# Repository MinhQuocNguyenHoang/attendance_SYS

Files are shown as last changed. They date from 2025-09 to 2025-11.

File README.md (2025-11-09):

# IoT Attendance System

## Overview
This is an IoT-based attendance system built using an ESP32 microcontroller.  
The device scans RFID cards to record attendance information (Card ID + Timestamp) and uploads the data in real time to Google Sheets for storage and monitoring.

**Future enhancements:** integrating fingerprint authentication for additional security and flexibility.

## Hardware Used
- MCU: ESP32 (WiFi + Bluetooth)
- RFID Module: RC522 (SPI)
- LCD: 16x02 via I2C
- Power supply + voltage regulator
- Custom PCB designed with Altium Designer

## Software Environment
- Language: Embedded C
- Framework: ESP-IDF v5.4.1
- RTOS: FreeRTOS real-time kernel
- Tools: VS Code, Altium Designer (PCB design)
- Library: abobija_rc522

## Project Structure
```
    attendance_SYS/
    ├─ attendance_SYS_altium/ # PCB design / schematic
    ├─ attendance_system/ # MCU code
    ├─ README.md # This file
    ├─ demo_IOT_attendance_sys.mp4 # Demo video
    ├─ layout.pdf # PCB layout
    └─ schematic.pdf # Schematic
```

## Features
- Scan RFID cards and verify card IDs
- Log attendance time (RTC or NTP sync)
- Upload attendance data to Google Sheets
- Wi-Fi provisioning via BLE
- FreeRTOS task flow:
    1. Read rfid
    2. Send data to google sheet via https method GET

## Wiring / Schematic
- [PCB Layout](./layout.pdf) 
- [Schematic](./schematic.pdf) 

## Getting Started
1. Install ESP-IDF 
2. Setup Google Sheets API: [Google Sheet](https://docs.google.com/spreadsheets/d/ 1bOf_m6btDb6PRxpN6TObC4pNcN5I2Ge17Xd1aixpjCk/edit?usp=sharing) 
3. Connect USB cable to flash and monitor ESP32 

```bash
git clone https://github.com/MinhQuocNguyenHoang/attendance_SYS.git
cd attendance_SYS/attendance_system
idf.py set-target esp32
idf.py build
idf.py flash monitor
```

## Demo
A demonstration video is included:
[Demo Video](./demo_IOT_attendance_sys.mp4)

## Testing
Scan RFID card → Data should instantly appear in Google Sheets<br> 
Test Wi-Fi Provisioning → Device must reconnect automatically

## Roadmap / Future Improvements
- Add fingerprint sensor for secure attendance 
- Retry & error handling to prevent data loss 
- Build a mobile/web dashboard for data visualization 
- Improve data security with message encryption
- OTA firmware to ESP32  

## Author
Nguyễn Hoàng Minh Quốc<br>
GitHub: @MinhQuocNguyenHoang

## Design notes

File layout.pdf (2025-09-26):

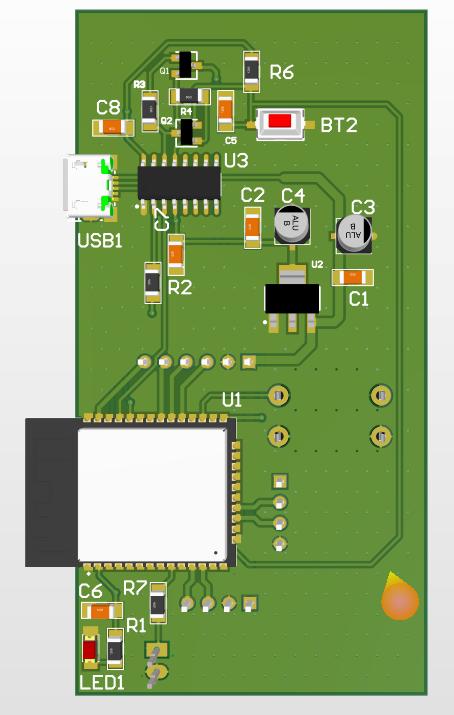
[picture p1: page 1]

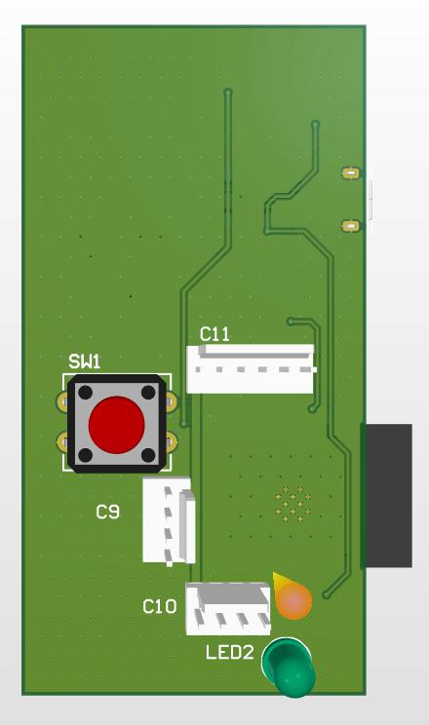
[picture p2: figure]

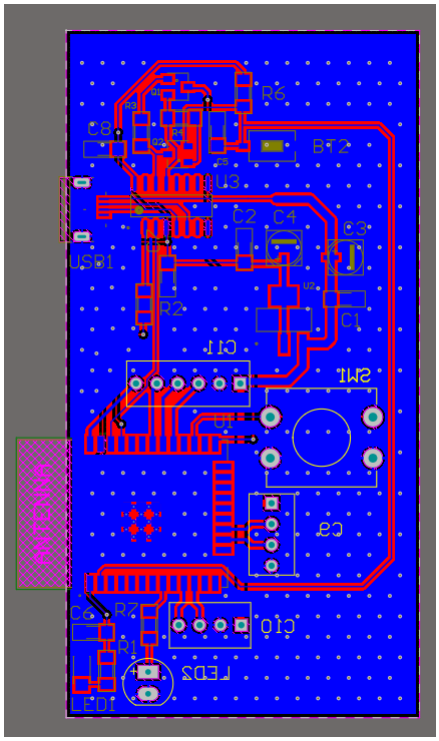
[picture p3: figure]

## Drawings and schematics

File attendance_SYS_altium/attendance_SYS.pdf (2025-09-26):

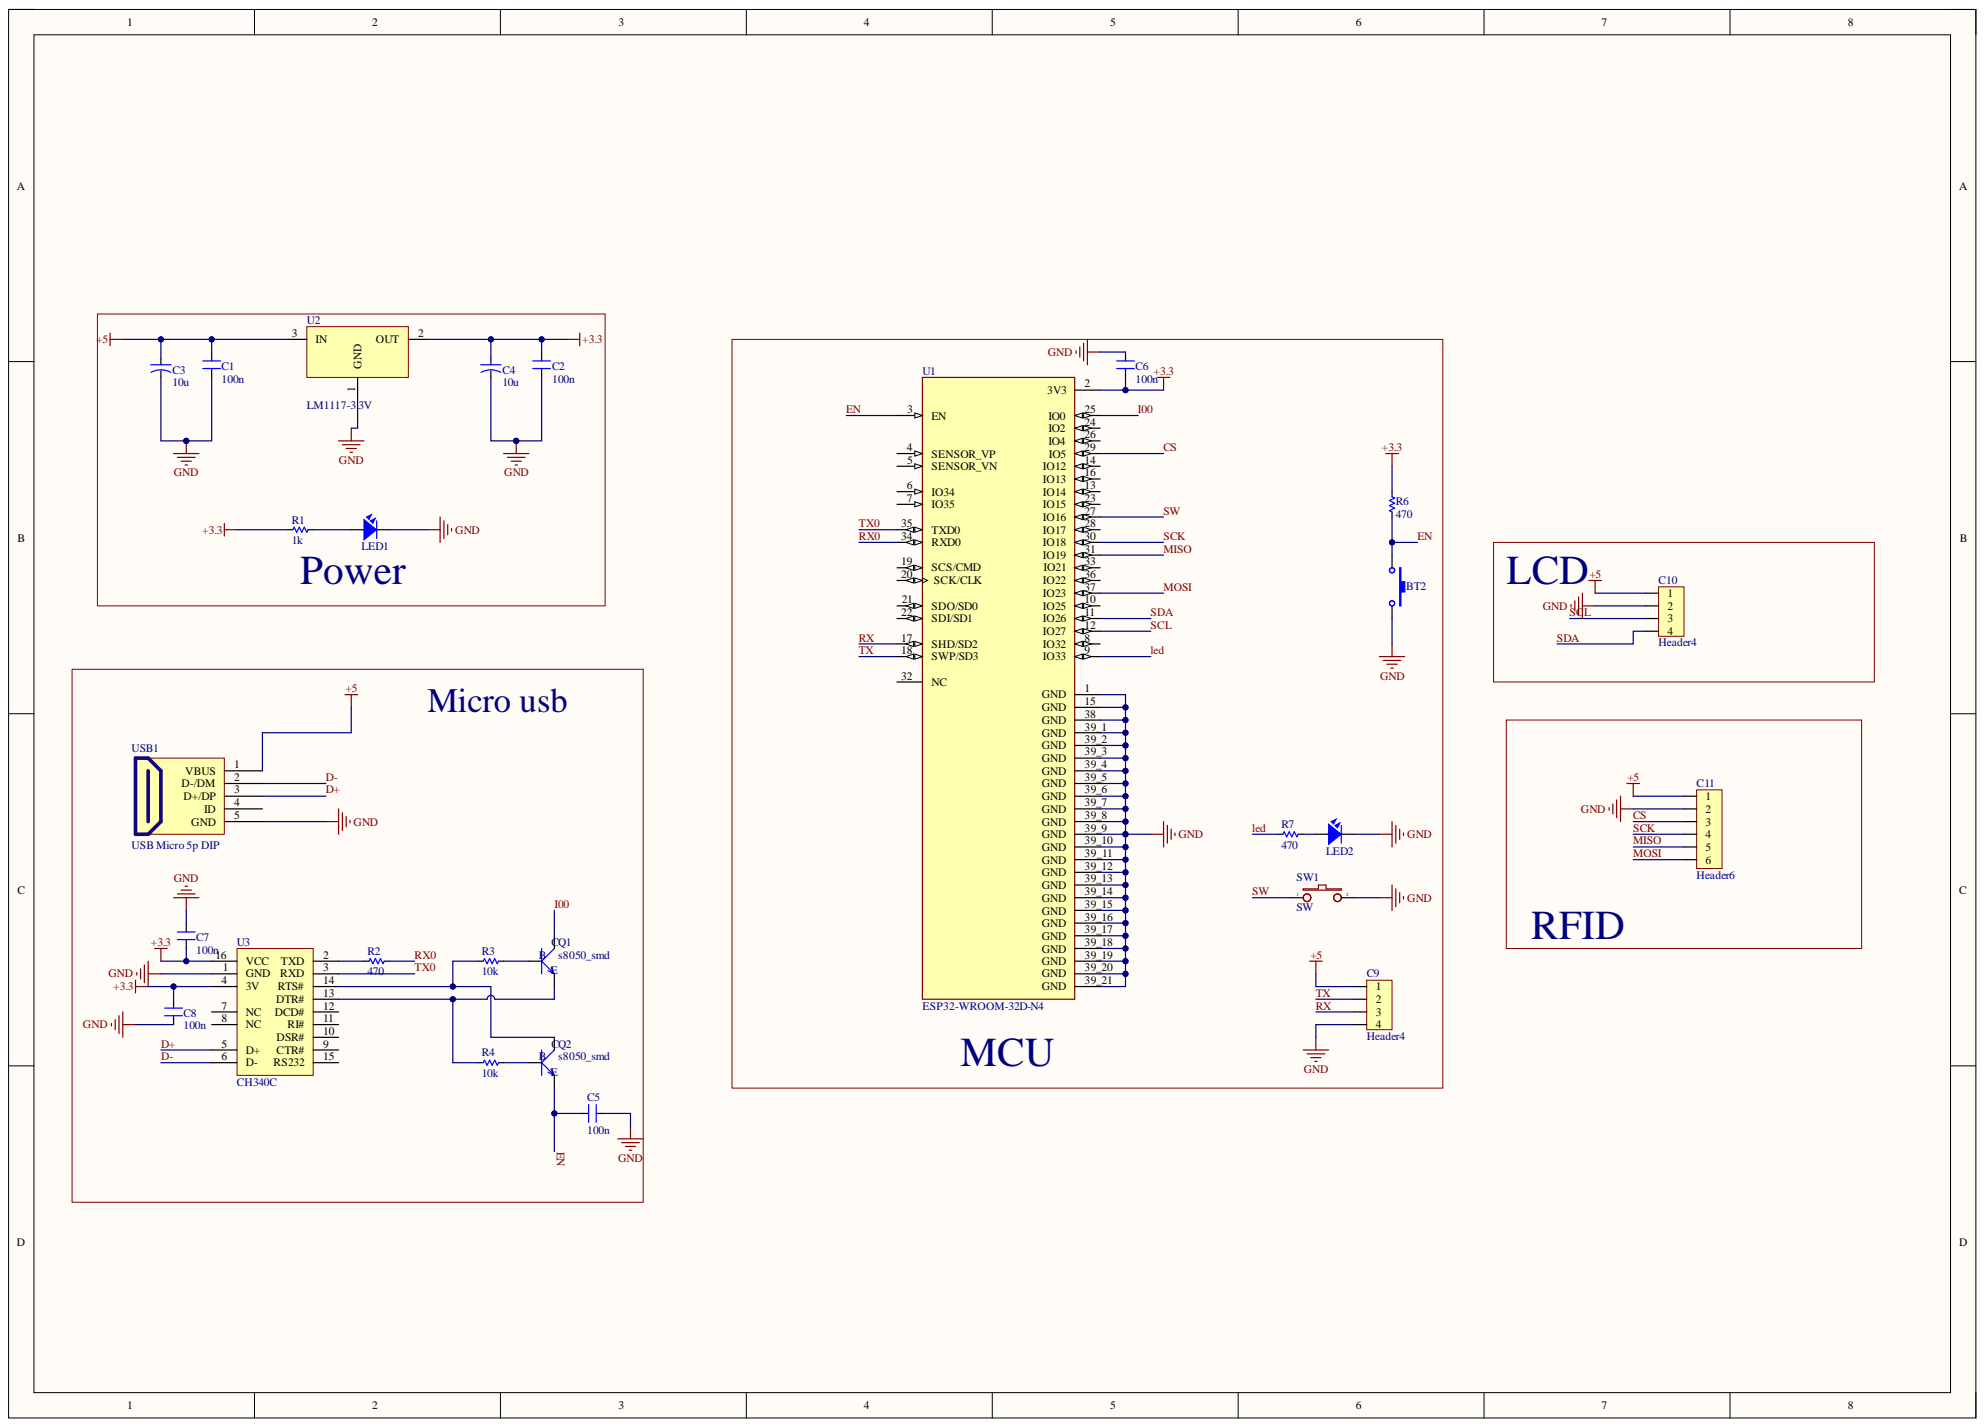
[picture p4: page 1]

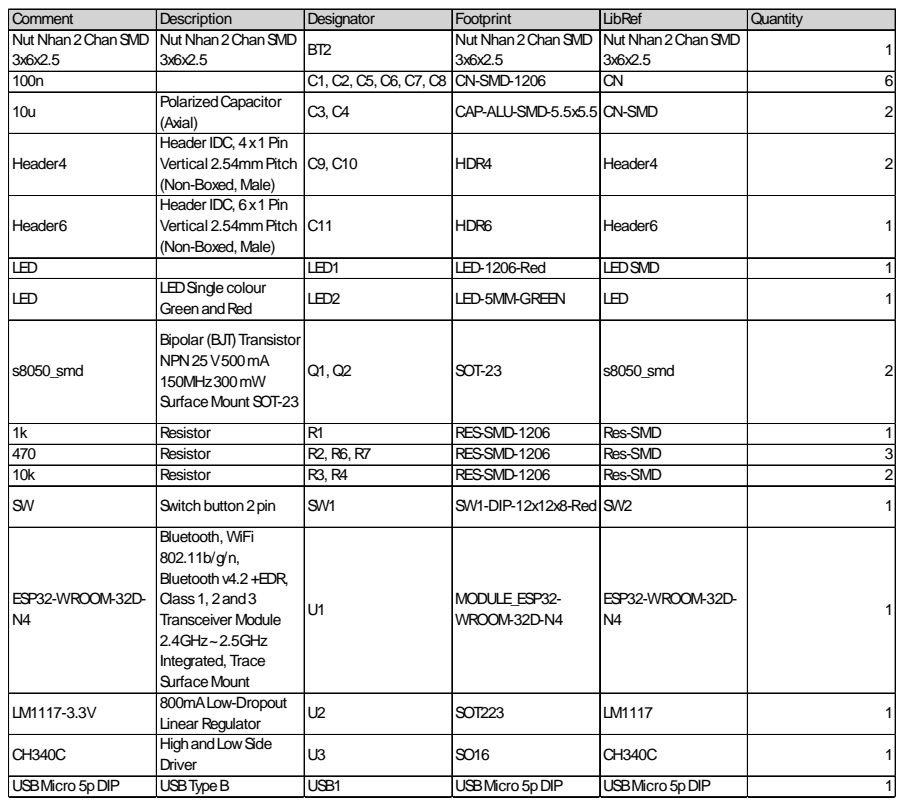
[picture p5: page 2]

Comment | Description | Designator | Footprint | LibRef | Quantity
Nut Nhan2ChanSMD 3x6x2.5 | Nut Nhan2ChanSMD 3x6x2.5 | BT2 | Nut Nhan2ChanSMD 3x6x2.5 | Nut Nhan2ChanSMD 3x6x2.5 | 1

100n | | C1, C2, C5, C6, C7, C8 | CN-SMD-1206 | CN | 6
10u | PolarizedCapacitor (Axial) | C3, C4 | CAP-ALU-SMD-5.5x5.5 | CN-SMD | 2

Header4 | Header IDC, 4x1Pin Vertical 2.54mmPitch (Non-Boxed, Male) | C9, C10 | HDR4 | Header4 | 2

Header6 | Header IDC, 6x1Pin Vertical 2.54mmPitch (Non-Boxed, Male) | C11 | HDR6 | Header6 | 1

LED | | LED1 | LED-1206-Red | LEDSMD | 1
LED | LEDSinglecolour GreenandRed | LED2 | LED-5MM-GREEN | LED | 1

s8050_smd | Bipolar (BJT)Transistor NPN25V500mA 150MHz300mW SurfaceMount SOT-23 | Q1, Q2 | SOT-23 | s8050_smd | 2

1k | Resistor | R1 | RES-SMD-1206 | Res-SMD | 1
470 | Resistor | R2, R6, R7 | RES-SMD-1206 | Res-SMD | 3
10k | Resistor | R3, R4 | RES-SMD-1206 | Res-SMD | 2

SW | Switch button2pin | SW1 | SW1-DIP-12x12x8-Red | SW2 | 1

ESP32-WROOM-32D-N4 | Bluetooth, WiFi 802.11b/g/n, Bluetoothv4.2+EDR, Class1, 2and3 Transceiver Module 2.4GHz~2.5GHz Integrated, Trace SurfaceMount | U1 | MODULE_ESP32-WROOM-32D-N4 | ESP32-WROOM-32D-N4 | 1

LM1117-3.3V | 800mALow-Dropout Linear Regulator | U2 | SOT223 | LM1117 | 1

CH340C | HighandLowSide Driver | U3 | SO16 | CH340C | 1

USBMicro 5pDIP | USBTypeB | USB1 | USBMicro 5pDIP | USBMicro 5pDIP | 1

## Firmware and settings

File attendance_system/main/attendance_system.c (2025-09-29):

#include <string.h>
#include <stdlib.h>
#include <stdio.h>
#include <string.h>
#include <stdlib.h>
#include <esp_log.h>
#include "rc522.h"
#include "driver/rc522_spi.h"
#include "rc522_picc.h"
#include "freertos/FreeRTOS.h"
#include "freertos/task.h"
#include "freertos/queue.h"
#include "time.h"
#include "driver_I2C.h"
#include "wifi.h"
#include "http.h"

static QueueHandle_t rfid_queue = NULL;
static const char *TAG_SYNC = "sync";
static const char *TAG = "rc522_ID";

#define RC522_SPI_BUS_GPIO_MISO (19)
#define RC522_SPI_BUS_GPIO_MOSI (23)
#define RC522_SPI_BUS_GPIO_SCLK (18)
#define RC522_SPI_SCANNER_GPIO_SDA (5)
#define RC522_SCANNER_GPIO_RST (-1) // soft-reset

#define UID_MAX_LEN RC522_PICC_UID_STR_BUFFER_SIZE_MAX

static rc522_spi_config_t driver_config = {
    .host_id = SPI3_HOST,
    .bus_config = &(spi_bus_config_t){
        .miso_io_num = RC522_SPI_BUS_GPIO_MISO,
        .mosi_io_num = RC522_SPI_BUS_GPIO_MOSI,
        .sclk_io_num = RC522_SPI_BUS_GPIO_SCLK,
    },
    .dev_config = {
        .spics_io_num = RC522_SPI_SCANNER_GPIO_SDA,
    },
    .rst_io_num = RC522_SCANNER_GPIO_RST,
};
static rc522_driver_handle_t driver;
static rc522_handle_t scanner;

static void on_picc_state_changed(void *arg, esp_event_base_t base, int32_t event_id, void *data)
{
    rc522_picc_state_changed_event_t *event = (rc522_picc_state_changed_event_t *)data;
    rc522_picc_t *picc = event->picc;

    if (picc->state == RC522_PICC_STATE_ACTIVE)
    {
        char uid_str[RC522_PICC_UID_STR_BUFFER_SIZE_MAX];
        esp_err_t ret = rc522_picc_uid_to_str(&picc->uid, uid_str, sizeof(uid_str));

        if (ret == ESP_OK)
        {
            lcd_clear();
            lcd_set_cursor(0, 0);
            lcd_send_string(uid_str);
            lcd_set_cursor(0, 1);
            lcd_send_string("dang gui");
            char uid_copy[UID_MAX_LEN];
            strlcpy(uid_copy, uid_str, sizeof(uid_copy));
            xQueueSend(rfid_queue, uid_copy, portMAX_DELAY);
        }
        else
        {
            ESP_LOGW(TAG, "Chuyển UID sang chuỗi thất bại");
        }
    }
    else if (picc->state == RC522_PICC_STATE_IDLE && event->old_state >= RC522_PICC_STATE_ACTIVE)
    {
        ESP_LOGI(TAG, "Card has been removed");
    }
}

void rfid_scanner_task(void *parameters)
{
    // Khởi tạo rc522
    rc522_spi_create(&driver_config, &driver);
    rc522_driver_install(driver);

    rc522_config_t scanner_config = {
        .driver = driver,
    };
    rc522_create(&scanner_config, &scanner);
    rc522_register_events(scanner, RC522_EVENT_PICC_STATE_CHANGED, on_picc_state_changed, NULL);
    lcd_set_cursor(0, 0);
    lcd_send_string("Moi ban quet the");
    rc522_start(scanner);
    while (1)
    {
        vTaskDelay(pdMS_TO_TICKS(100));
    }
}

void http_post_task(void *parameters)
{
    char uid_buffer[UID_MAX_LEN];
    while (1)
    {
        if (xQueueReceive(rfid_queue, uid_buffer, portMAX_DELAY) == pdPASS)
        {
            rc522_pause(scanner);
            uid_buffer[UID_MAX_LEN - 1] = '\0';
            send_data_to_sheet(uid_buffer);
            rc522_start(scanner);
        }
    }
}

void app_main()
{
    rfid_queue = xQueueCreate(5, UID_MAX_LEN);
    if (rfid_queue == NULL)
    {
        ESP_LOGE(TAG, "Failed to create RFID queue");
    }

    // khởi tạo LCD
    i2c_master_init();
    i2c_scanner();
    lcd_init();

    // khởi tạo wifi
    wifi_provising_config();

    // chạy task
    xTaskCreate(&http_post_task, "http", 4096, NULL, 4, NULL);
    xTaskCreate(&rfid_scanner_task, "rfid", 8000, NULL, 5, NULL);
}

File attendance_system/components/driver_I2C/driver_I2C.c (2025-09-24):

#include "driver_I2C.h"
#include "freertos/FreeRTOS.h"
#include "freertos/task.h"
#include <esp_log.h>

#define I2C_MASTER_SCL_IO (22)
#define I2C_MASTER_SDA_IO (21)
#define I2C_MASTER_NUM I2C_NUM_0
#define I2C_MASTER_FREQ_HZ (100000)
#define LCD_COMMAND 0
#define LCD_DATA 1
#define LCD_ADDRESS 0x27
#define LCD_BACKLIGHT 0x08
#define LCD_ENABLE 0x04
#define LCD_RS 0x01

static uint8_t lcd_adr = LCD_ADDRESS;
static const char *TAG_I2C = "I2C";

// hàm nội bộ
static void lcd_send_i2c(uint8_t data)
{
    i2c_master_write_to_device(I2C_MASTER_NUM, LCD_ADDRESS, &data, 1, pdMS_TO_TICKS(1000));
}

static void lcd_strobe(uint8_t data)
{
    lcd_send_i2c(data | LCD_ENABLE | LCD_BACKLIGHT);
    vTaskDelay(pdMS_TO_TICKS(1));
    lcd_send_i2c((data & ~LCD_ENABLE) | LCD_BACKLIGHT);
    vTaskDelay(pdMS_TO_TICKS(1));
}

static void lcd_send_4bit(uint8_t nibble, uint8_t rs_flag)
{
    uint8_t data = (nibble << 4); // D4~D7 nằm tại P4~P7
    if (rs_flag)
        data |= LCD_RS;
    data |= LCD_BACKLIGHT;
    lcd_strobe(data);
}

static void lcd_send_8bit(uint8_t byte, uint8_t rs_flag)
{
    lcd_send_4bit(byte >> 4, rs_flag);
    lcd_send_4bit(byte & 0x0F, rs_flag);
}

// hàm public
void i2c_scanner()
{
    ESP_LOGI(TAG_I2C, "Scanning I2C bus...");
    for (int addr = 1; addr < 127; addr++)
    {
        i2c_cmd_handle_t cmd = i2c_cmd_link_create();
        i2c_master_start(cmd);
        i2c_master_write_byte(cmd, (addr << 1) | I2C_MASTER_WRITE, true);
        i2c_master_stop(cmd);
        esp_err_t ret = i2c_master_cmd_begin(I2C_MASTER_NUM, cmd, pdMS_TO_TICKS(100));
        i2c_cmd_link_delete(cmd);

        if (ret == ESP_OK)
        {
            ESP_LOGI(TAG_I2C, "I2C device found at address 0x%02X", addr);
        }
    }
}

void i2c_master_init()
{
    i2c_config_t conf = {
        .mode = I2C_MODE_MASTER,
        .sda_io_num = I2C_MASTER_SDA_IO,
        .scl_io_num = I2C_MASTER_SCL_IO,
        .sda_pullup_en = GPIO_PULLUP_ENABLE,
        .scl_pullup_en = GPIO_PULLUP_ENABLE,
        .master.clk_speed = I2C_MASTER_FREQ_HZ,
    };
    i2c_param_config(I2C_MASTER_NUM, &conf);
    i2c_driver_install(I2C_MASTER_NUM, conf.mode, 0, 0, 0);
}

void lcd_command(uint8_t cmd)
{
    lcd_send_8bit(cmd, 0);
}

void lcd_send_data(uint8_t data)
{
    lcd_send_8bit(data, LCD_RS);
}

void lcd_set_cursor(uint8_t col, uint8_t row)
{
    const uint8_t row_offsets[] = {0x00, 0x40, 0x14, 0x54};
    lcd_command(0x80 | (col + row_offsets[row]));
}

void lcd_send_string(const char *str)
{
    while (*str)
    {
        lcd_send_data(*str++);
    }
}

void lcd_init()
{
    vTaskDelay(pdMS_TO_TICKS(50));
    lcd_send_4bit(0x03, 0);
    vTaskDelay(pdMS_TO_TICKS(5));
    lcd_send_4bit(0x03, 0);
    vTaskDelay(pdMS_TO_TICKS(1));
    lcd_send_4bit(0x03, 0);
    lcd_send_4bit(0x02, 0);

    lcd_command(0x28); // Function Set: 4-bit, 2 dòng, font 5x8
    lcd_command(0x0C); // Display Control: Bật màn hình, tắt con trỏ
    lcd_command(0x06); // Entry Mode Set: Tự động tăng con trỏ
    lcd_command(0x01); // Xóa màn hình
    vTaskDelay(pdMS_TO_TICKS(2));
}

void lcd_clear()
{
    lcd_command(0x01);
    vTaskDelay(pdMS_TO_TICKS(2));
}

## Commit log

2025-09-07 Update layout
    Thí commit change polygon connect.
    [attendance_SYS.PcbDoc]
2025-09-15 Successfully version
    [attendance_SYS.PcbDoc]
2025-09-26 Update finally
    [attendance_SYS.PcbDoc, attendance_SYS.PrjPcb, attendance_SYS.SchDoc]
2025-11-14 Add attendance_system submodule
    [partitions.csv]
